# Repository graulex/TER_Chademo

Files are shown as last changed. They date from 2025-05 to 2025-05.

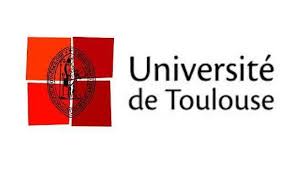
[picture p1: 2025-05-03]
Code/IHM/téléchargement.jpeg

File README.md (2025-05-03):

# Projet TER – Communication CAN avec STM32 pour la recharge CHAdeMO

##  Introduction

Ce dépôt GitHub présente le travail réalisé dans le cadre du **projet TER** intitulé :

**_Conception de cartes de communication CAN sur la base d’un microcontrôleur STM32 pour l’émulation de la gestion de charge de la voiture électrique avec le protocole CHAdeMO._**

Ce projet a été mené par :

- **Alexandre Guilcher**  
- **Damien Gonfo**  
- **Salah Ouaret**  

Sous la direction de **Damian Sal y Rosas**.

---

##  Organisation du dépôt

### `code/`
Contient l'ensemble des codes sources du projet :
-  **Code C STM32 - Borne de recharge (EVSE)** : développé avec STM32CubeIDE, implémente la logique de communication CHAdeMO côté borne.
-  **Code C STM32 - Véhicule électrique (EV)** : développé également sur STM32CubeIDE, simule le comportement d’un véhicule compatible CHAdeMO.
-  **Interface MATLAB** : IHM développée sous MATLAB permettant de communiquer avec la borne via une interface série (USART). Elle permet de lancer ou arrêter la charge et de suivre l’état de la batterie depuis un ordinateur.

---

### `documentation/`
Regroupe les ressources techniques utilisées :
-  **Articles scientifiques**
-  **Documentation technique officielle IEEE**

---

### `doxygen/`
Documentation logicielle générée automatiquement avec **Doxygen** :  
Décrit les fonctions, structures et comportements du code C (borne et véhicule).

---

### `uml/`
Diagrammes UML utilisés pendant la phase de conception :
- Diagrammes de cas d’usage
- Diagrammes de séquence
- Diagrammes de classes pour le logiciel embarqué de la borne et du véhicule
- Machines à états du véhicule et de la borne

---

### `kicad/`
Plans électroniques créés avec **KiCad** :
- 🛠 **Carte Borne de Recharge**
-  **Carte Véhicule Électrique**

Ces schémas permettent la fabrication physique des deux cartes de communication basées sur le protocole CAN.

---

##  Remarques

- Ce projet met en œuvre une **communication CAN bas-niveau**, conforme au protocole **CHAdeMO**, simulée entre une "borne" et un "véhicule" via des cartes STM32.
- L'IHM MATLAB agit comme un **outil de supervision et de contrôle**, permettant de **déclencher** et **suivre** une session de charge.

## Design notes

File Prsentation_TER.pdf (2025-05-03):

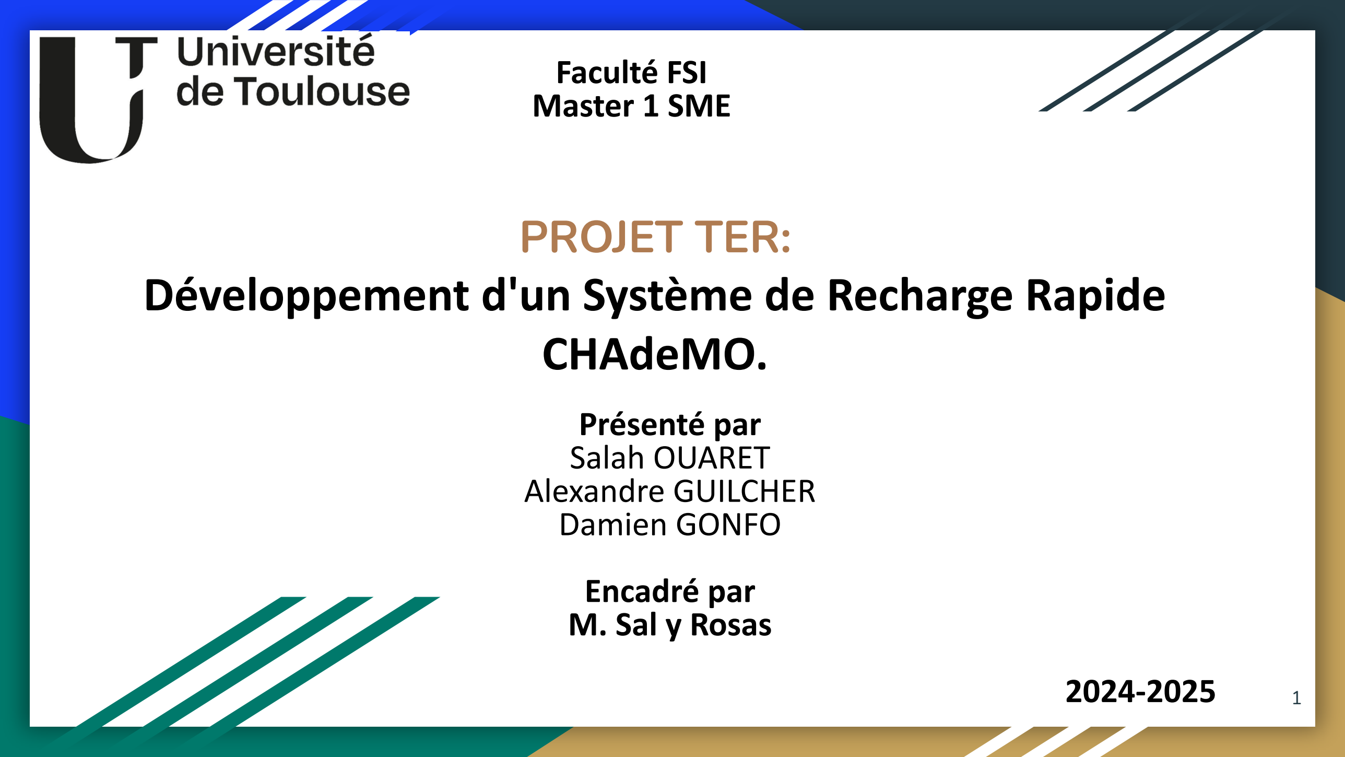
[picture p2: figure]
PROJET TER:; CHAdeMO.; Faculté FSI Master 1 SME; Présenté par Salah OUARET Alexandre GUILCHER Damien GONFO; Encadré par M. Sal y Rosas

## Développement d'un Système de Recharge Rapide

# Plan

### 1. Introduction

### 2. Etat de l’art

### 3. Analyse fonctionnelle

### 4. Protocole CHAdeMO

### 5. Présentation du montage

### 6. Trames CAN

### 7. Séquence de fonctionnement d’une recharge

### 8. Schématisation électronique

### 9. Conclusion

2

# 1. Introduction

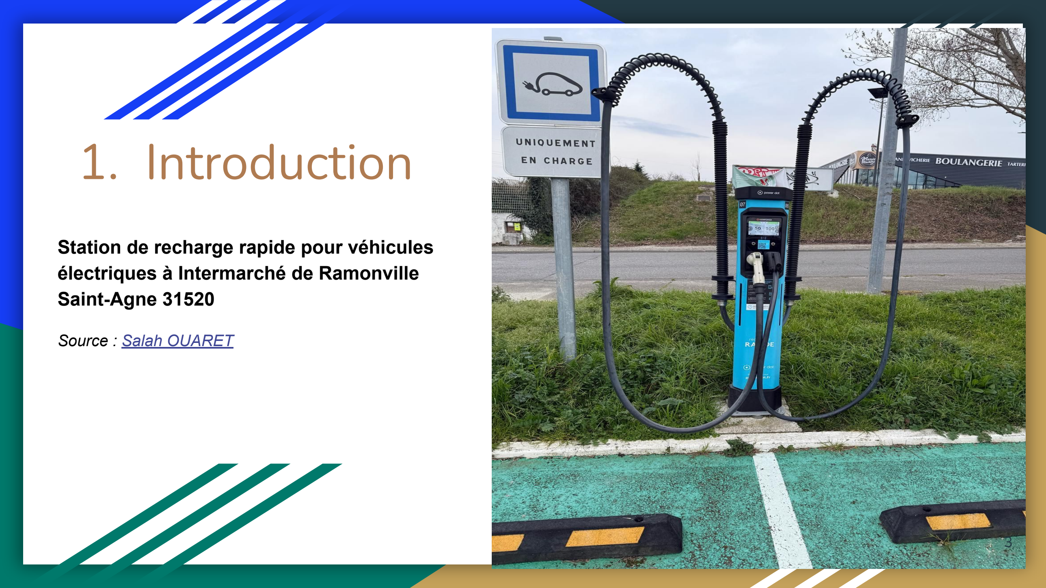
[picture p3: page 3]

Station de recharge rapide pour véhicules électriques à Intermarché de Ramonville Saint-Agne 31520

Source : Salah OUARET

3

# 2. Etat de l’art

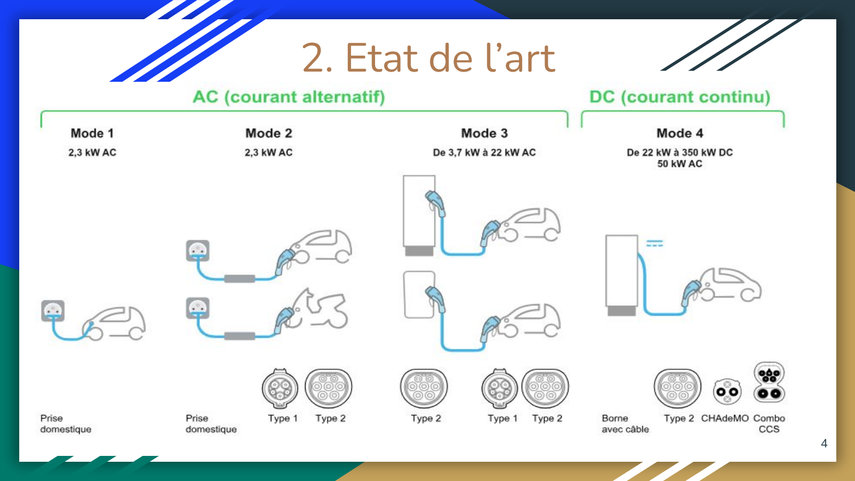
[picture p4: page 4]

4

# 3. Analyse fonctionnelle

5

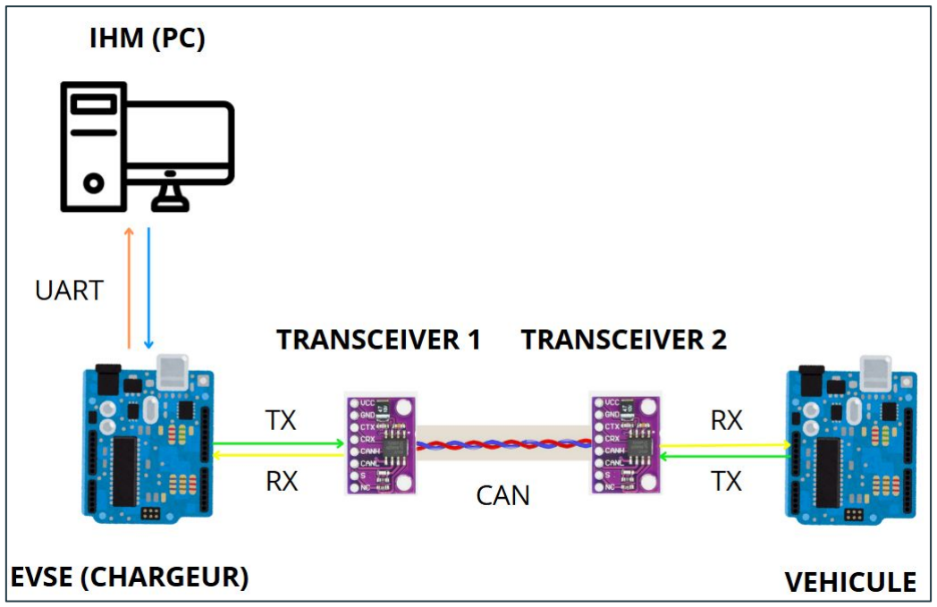
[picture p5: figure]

- Système composé de 2 cartes STM32 (EV et EVSE)
- Communication via bus CAN
- Machine à états pour gérer les phases de charge
- Exigences matérielles et logicielles (Interface IHM sous MATLAB, STM32CubeIDE)
- Diagrammes UML : contexte, cas d'utilisation, séquences

# 4. Protocole CHAdeMO

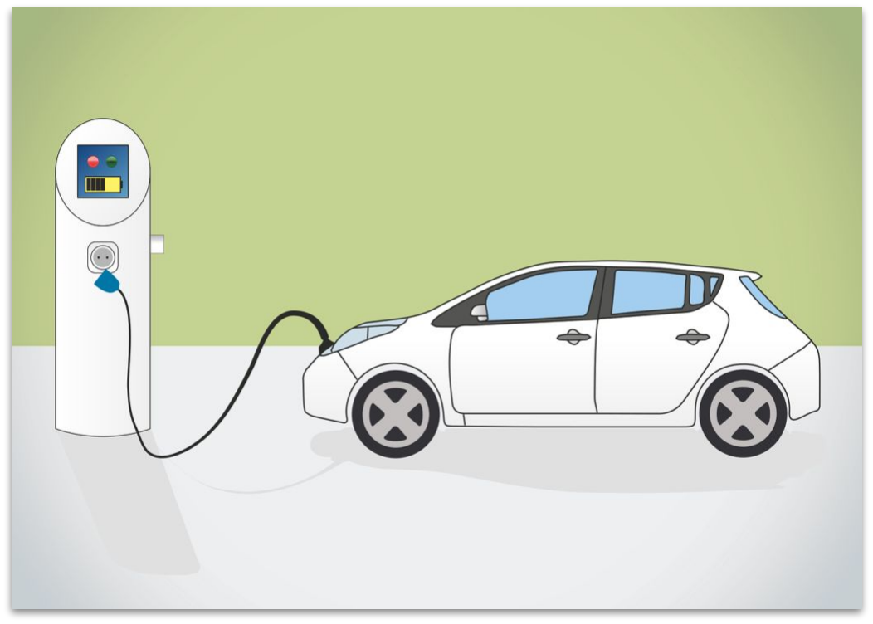
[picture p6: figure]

6

- Standard DC
- Communication CAN
- Échanges d’information véhicule / borne de recharge
- V2X : Vehicle to Everything
- V2G : Vehicle to Grid
- V2N : Vehicle to Network

# 5. Présentation du montage

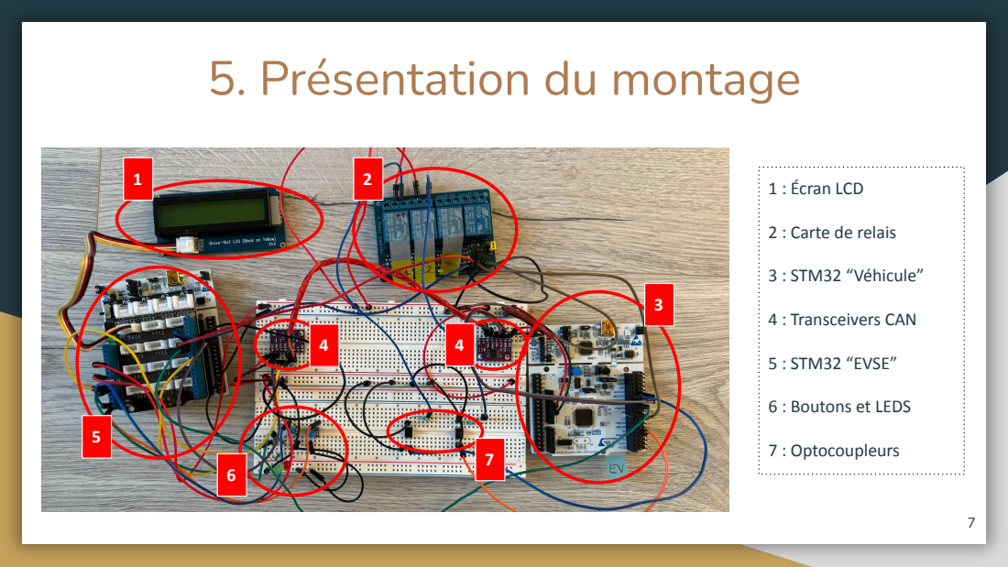
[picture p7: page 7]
1 : Écran LCD; 3 : STM32 “Véhicule”; 4 : Transceivers CAN; 5 : STM32 “EVSE”; 7 : Optocoupleurs

2 : Carte de relais

6 : Boutons et LEDS

# 6. Trames CAN

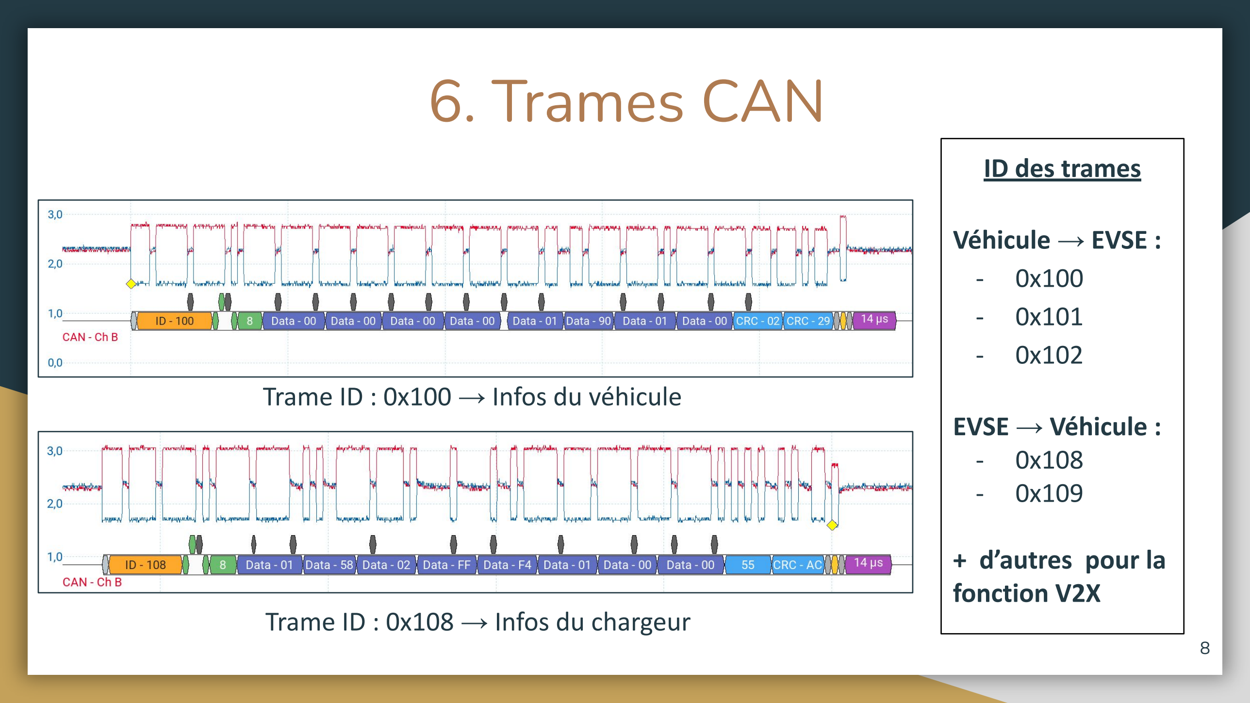
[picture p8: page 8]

ID des trames

Véhicule → EVSE :
- 0x100
- 0x101
- 0x102

EVSE → Véhicule :
- 0x108
- 0x109

+ d’autres pour la
fonction V2X

Trame ID : 0x100 → Infos du véhicule

Trame ID : 0x108 → Infos du chargeur
8

# 7. Séquence de fonctionnement d’une recharge

Signaux :
- d1 (Premier signal de séquence de charge)
- d2 (Second signal de séquence de charge)
- K (Permission de charge)
- CAN HIGH
- CAN LOW

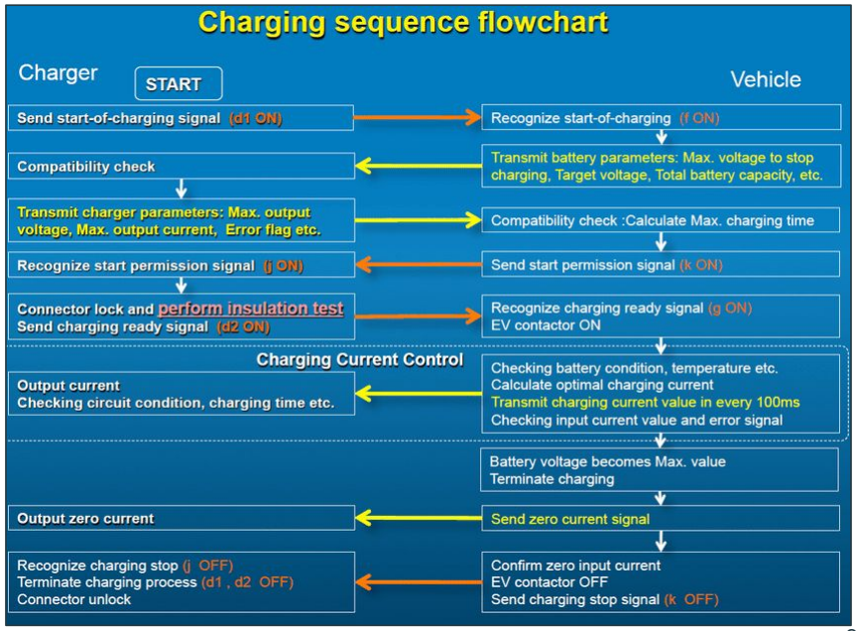
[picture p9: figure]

https://www.researchgate.net/figure/Flow-diagram-of-the-CHAdeMO-chagrining-protocol_fig4_319162700 9

# 8. Schéma électrique général

10

Configuration générale :

- EVSE (chargeur) et EV (véhicule)
- Positionnement des relais
- Références pour le CAN

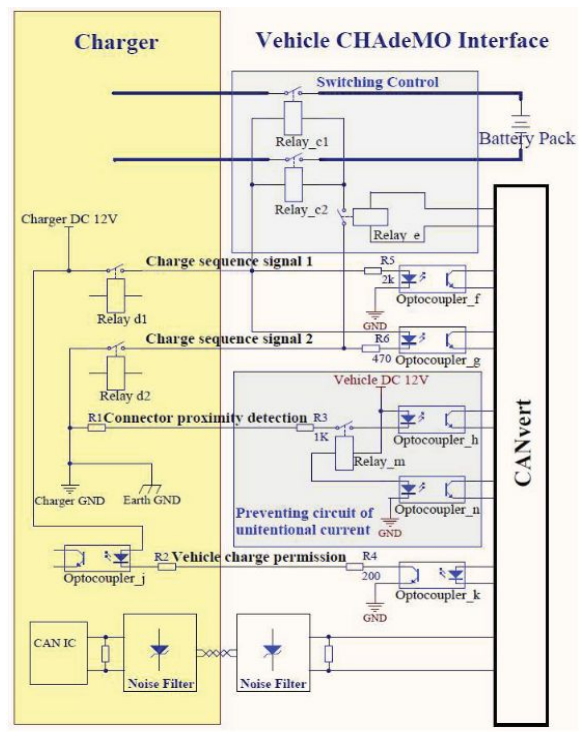
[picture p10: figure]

B.Sampath Kumar, Design and implementation of a CHAdeMO Interface on-board vehicle for vehicle-to-grid Applications, The International journal of analytical and experimental modal analysis

# 9. Schéma électrique partie EVSE

11

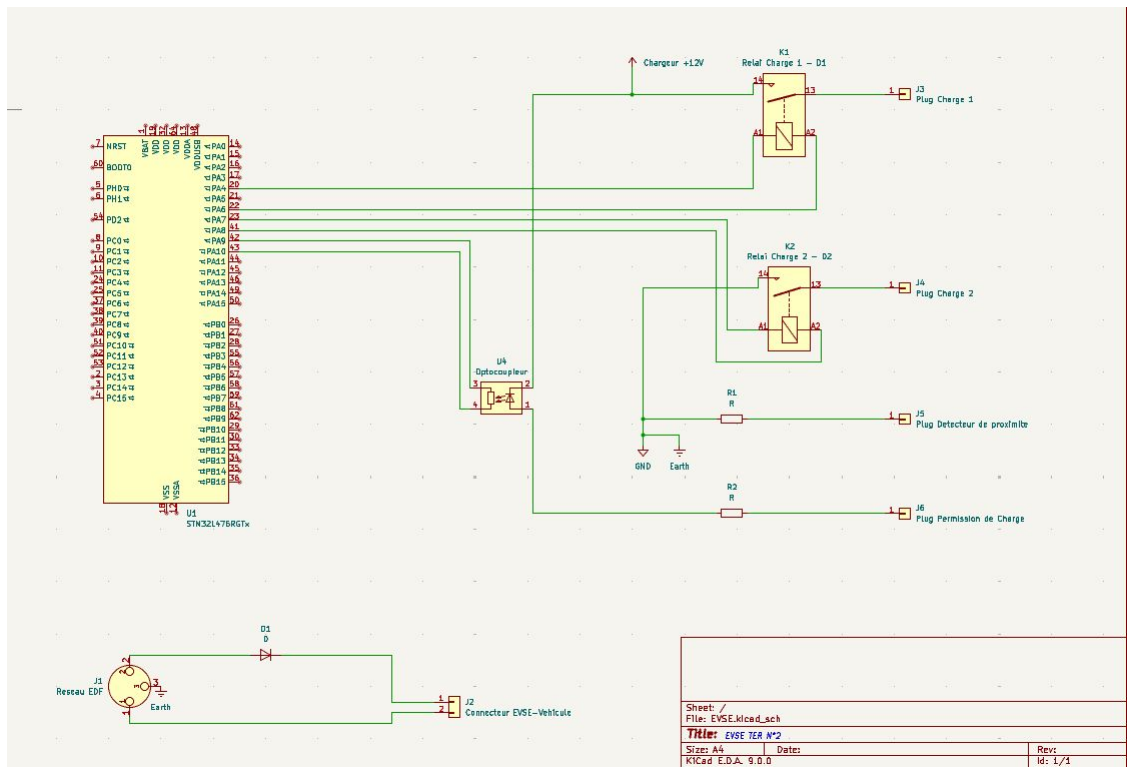
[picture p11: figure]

# 10. Modélisation 3D PCB partie EVSE

12

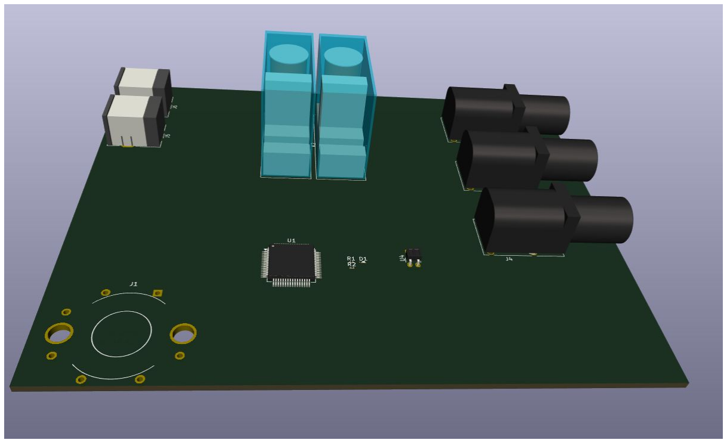
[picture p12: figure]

# 11. Schéma électrique partie EV

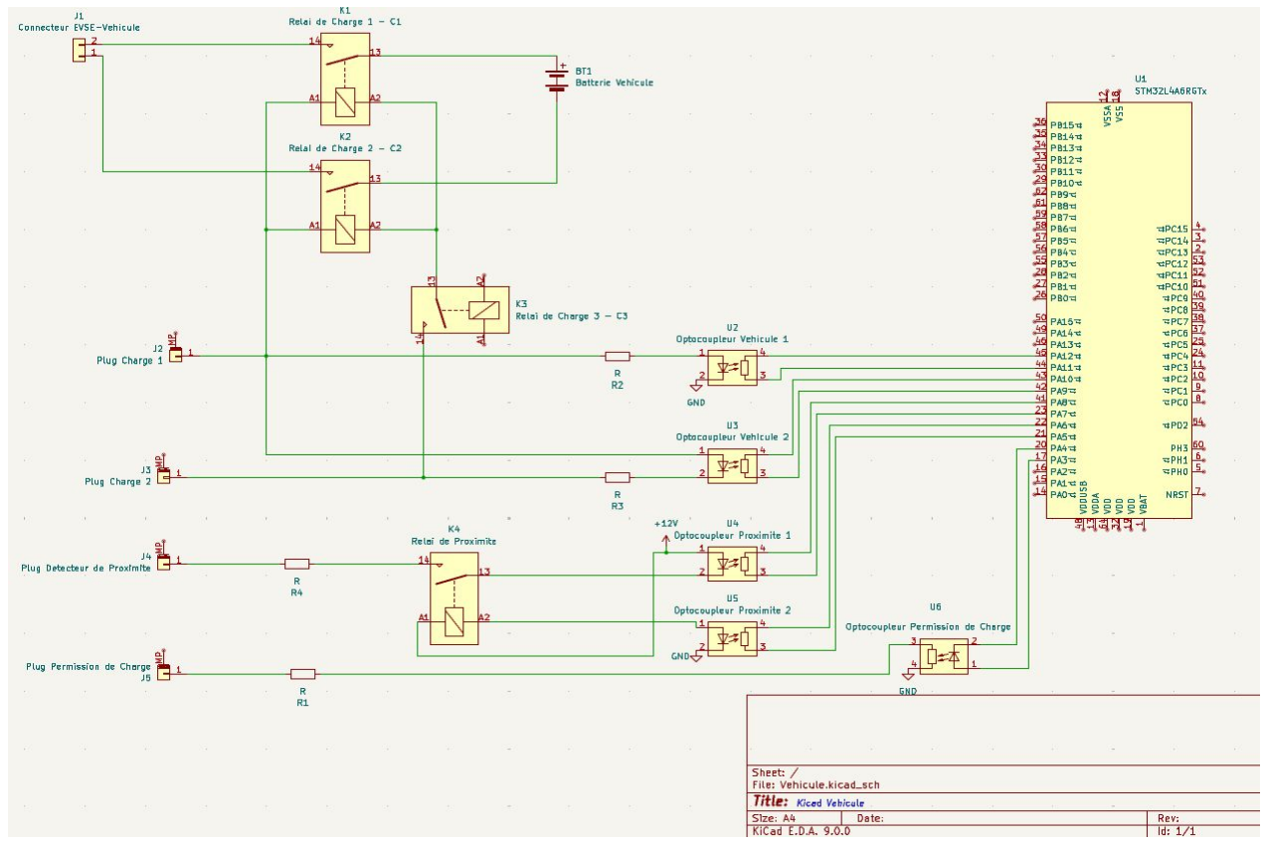
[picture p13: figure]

13

# 12. Modélisation 3D PCB partie EV

14

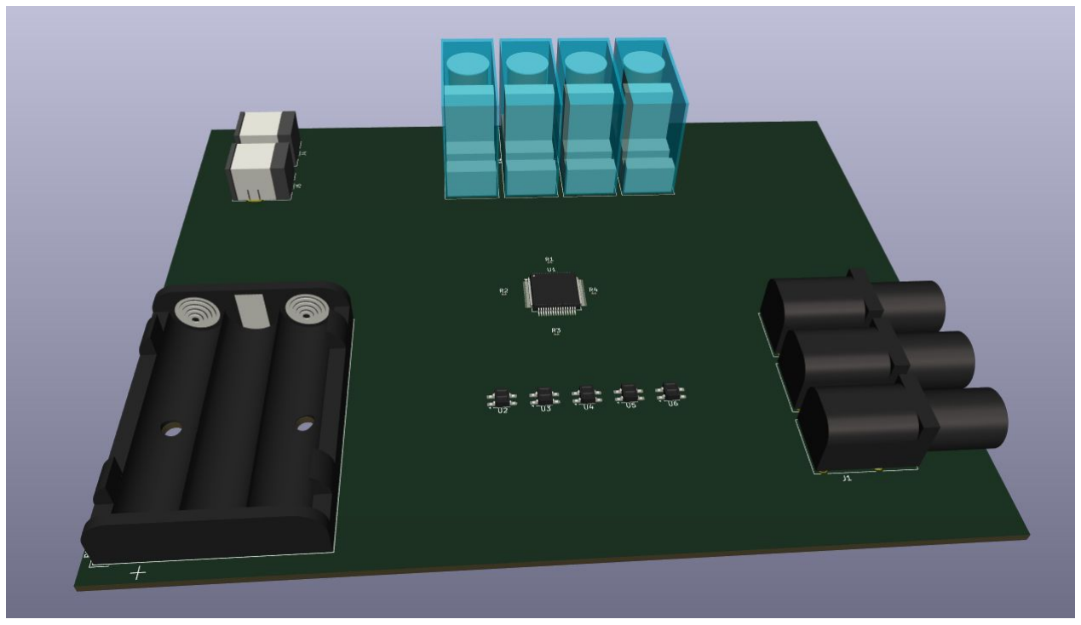
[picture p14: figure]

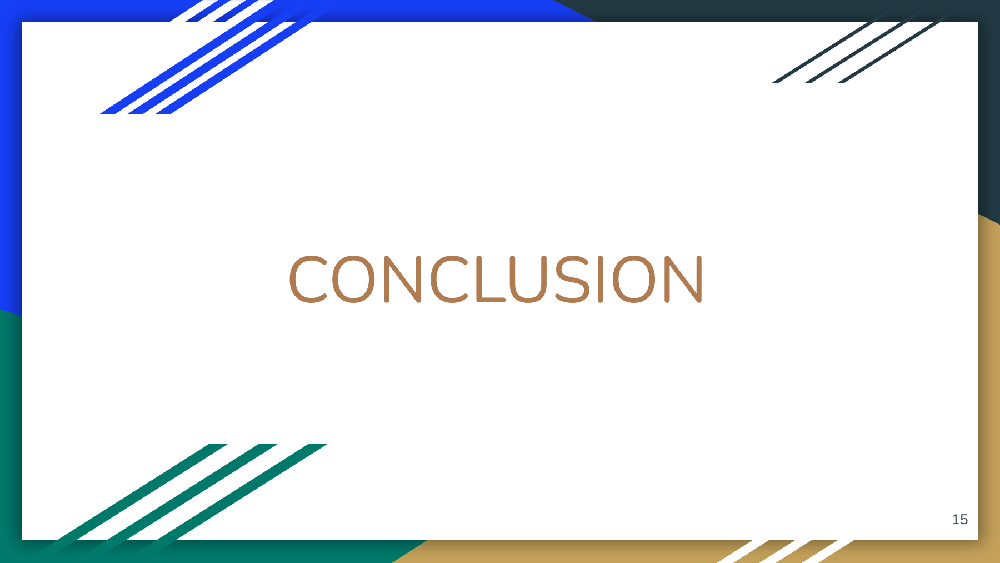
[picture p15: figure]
CONCLUSION

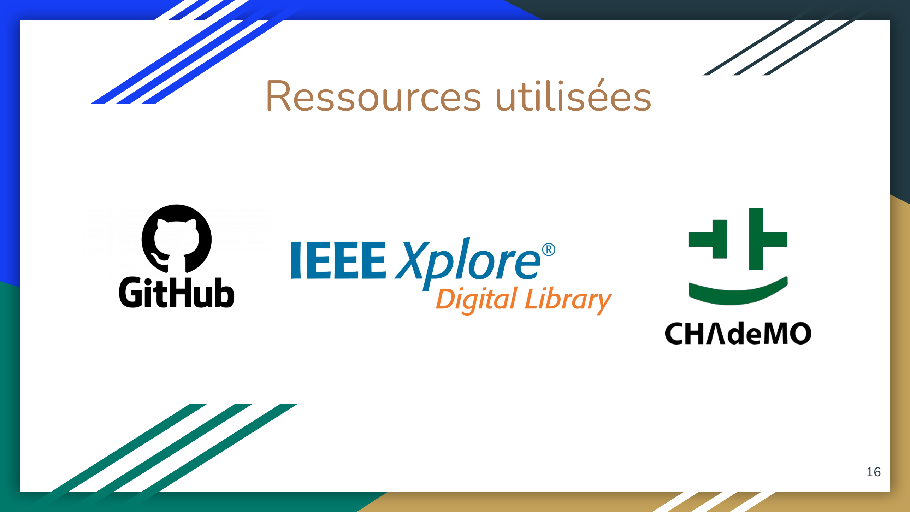
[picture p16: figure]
Ressources utilisées

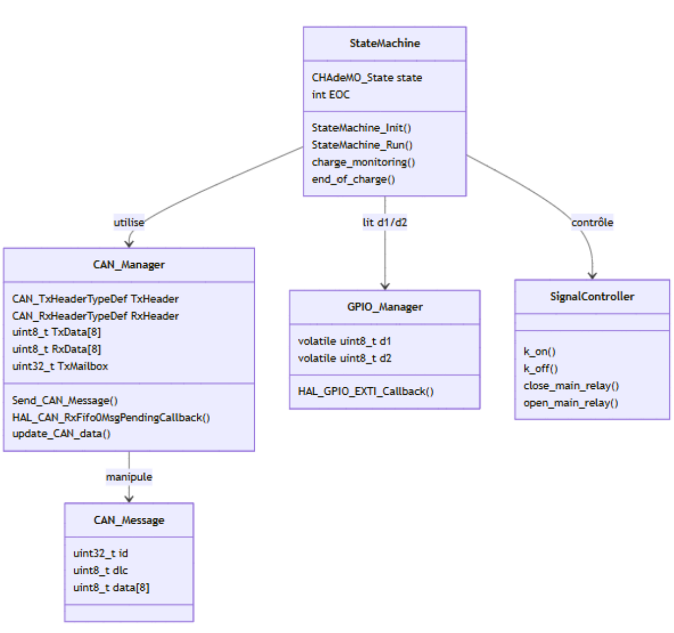
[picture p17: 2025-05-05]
Diagrammes UML/Diagramme de classes EV.png

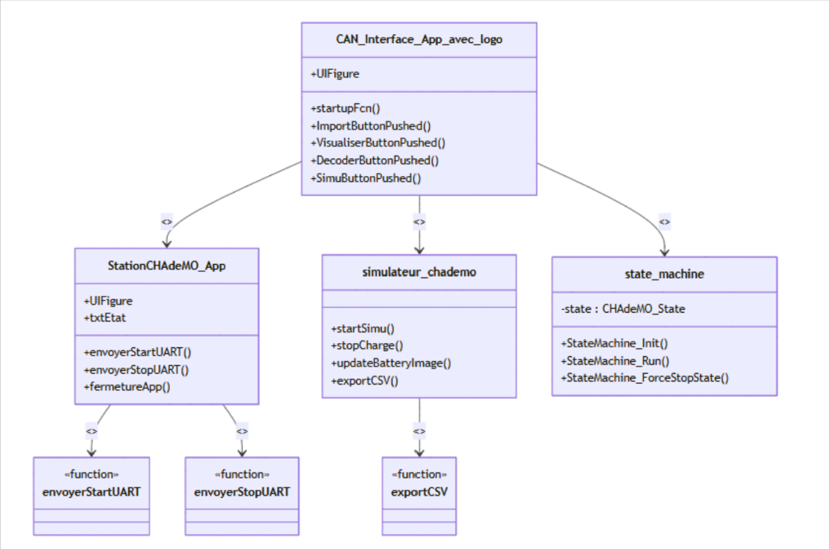
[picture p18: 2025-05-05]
Diagrammes UML/Diagramme de classes IHM.png

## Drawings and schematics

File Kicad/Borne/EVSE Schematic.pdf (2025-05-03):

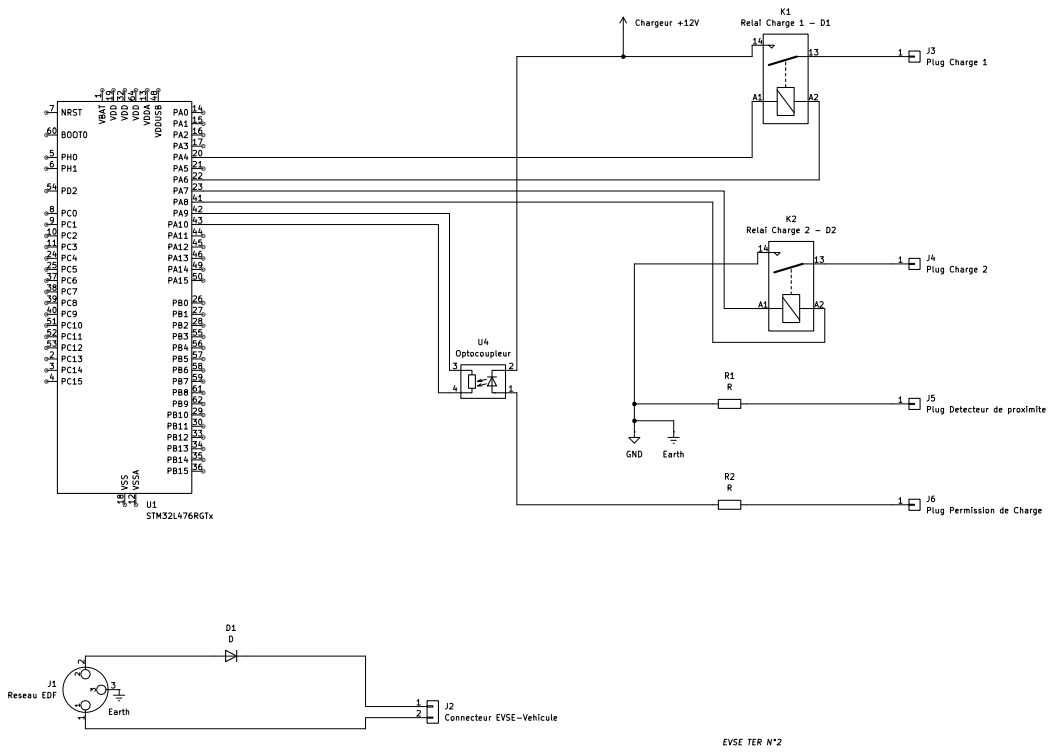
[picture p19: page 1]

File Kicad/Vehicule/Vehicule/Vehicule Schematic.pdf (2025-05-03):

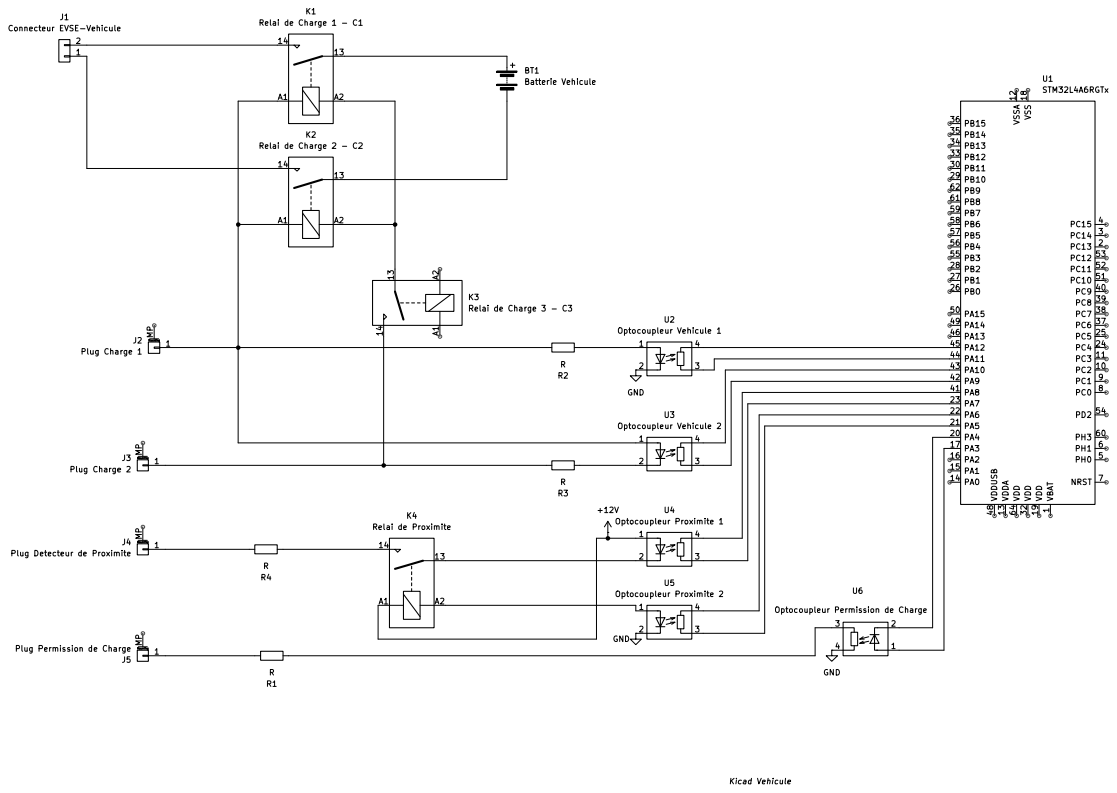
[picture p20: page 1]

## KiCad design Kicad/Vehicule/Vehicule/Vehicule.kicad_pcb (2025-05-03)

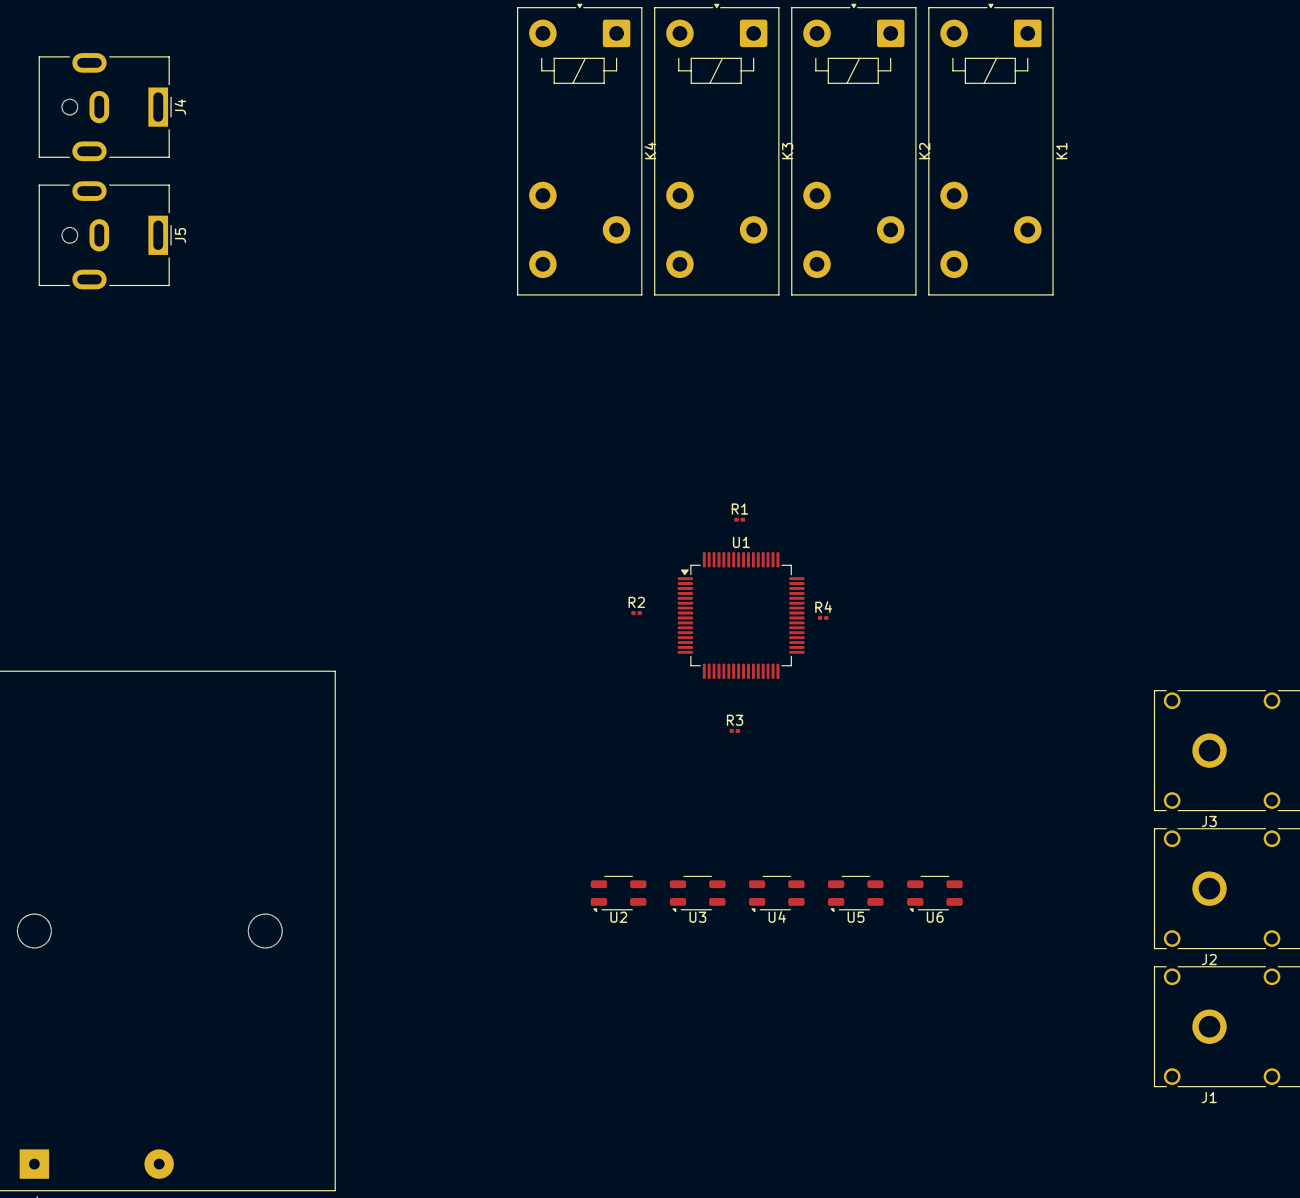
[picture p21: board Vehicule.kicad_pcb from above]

Board: 2 copper layers, 20 parts (0 on the bottom side), 24 nets, no tracks yet.

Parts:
BT1: Batterie Vehicule; BatteryHolder_Keystone_2479_3xAAA
J1: Connecteur EVSE-Vehicule; Banana_Cliff_FCR7350B_S16N-PC_Horizontal
J2: Plug Charge 1; Banana_Cliff_FCR7350B_S16N-PC_Horizontal
J3: Plug Charge 2; Banana_Cliff_FCR7350B_S16N-PC_Horizontal
J4: Plug Detecteur de Proximite; BarrelJack_CUI_PJ-063AH_Horizontal
J5: Plug Permission de Charge; BarrelJack_CUI_PJ-063AH_Horizontal
K1: Relai de Charge 1 - C1; Relay_SPDT_Finder_40.31
K2: Relai de Charge 2 - C2; Relay_SPDT_Finder_40.31
K3: Relai de Charge 3 - C3; Relay_SPDT_Finder_40.31
K4: Relai de Proximite; Relay_SPDT_Finder_40.31
R1, R2, R3, R4: R; R_0201_0603Metric
U1: STM32L4A6RGTx; LQFP-64_10x10mm_P0.5mm
U2: Optocoupleur Vehicule 1; OnSemi_CASE100CY
U3: Optocoupleur Vehicule 2; OnSemi_CASE100CY
U4: Optocoupleur Proximite 1; OnSemi_CASE100CY
U5: Optocoupleur Proximite 2; OnSemi_CASE100CY
U6: Optocoupleur Permission de Charge; OnSemi_CASE100CY

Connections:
+12V: K4.A1, U4.1 (A)
GND: U2.2 (K), U5.2 (K), U6.4 (R)
unnamed: J1.1, K2.14
unnamed: J2.1, K1.A1, K2.A1, R2.2, U3.1 (A)
unnamed: J3.1, K3.14, R3.2
unnamed: J4.1, R4.2
unnamed: J5.1, R1.2
unnamed: K1.A2, K2.A2
unnamed: K4.14, R4.1
unnamed: R1.1, U6.3 (R)
unnamed: U1.17 (PA3), U6.1 (A)
unnamed: U1.20 (PA4), U6.2 (K)
unnamed: U1.21 (PA5), U5.3 (R)
unnamed: U1.22 (PA6), U5.4 (R)
unnamed: U1.23 (PA7), U4.3 (R)
unnamed: U1.41 (PA8), U4.4 (R)
unnamed: U1.42 (PA9), U3.3 (R)
unnamed: U1.43 (PA10), U3.4 (R)
unnamed: U1.44 (PA11), U2.3 (R)
unnamed: U1.45 (PA12), U2.4 (R)
unnamed: U1.18 (VSS), U1.31 (VSS), U1.47 (VSS), U1.63 (VSS)
unnamed: R2.1, U2.1 (A)
unnamed: R3.1, U3.2 (K)
unnamed: K4.A2, U5.1 (A)

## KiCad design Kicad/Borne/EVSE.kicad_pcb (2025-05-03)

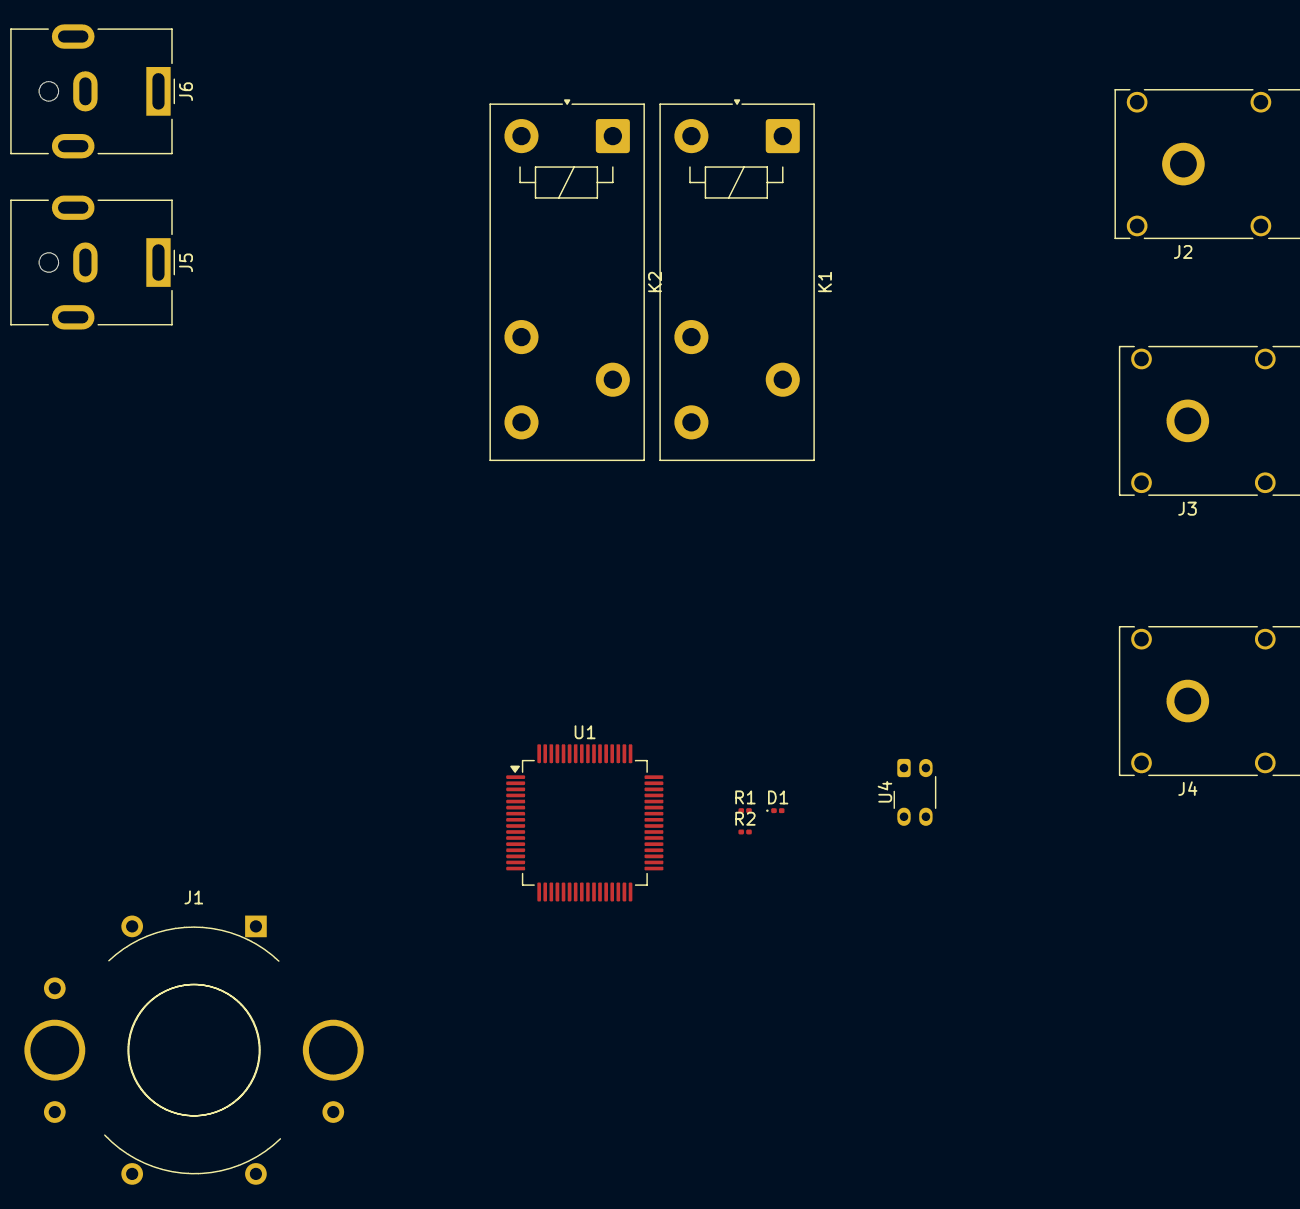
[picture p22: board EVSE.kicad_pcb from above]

Board: 2 copper layers, 13 parts (0 on the bottom side), 14 nets, no tracks yet.

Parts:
D1: D; LED_0201_0603Metric
J1: Reseau EDF; Valve_Mini_G
J2: Connecteur EVSE-Vehicule; Banana_Cliff_FCR7350B_S16N-PC_Horizontal
J3: Plug Charge 1; Banana_Cliff_FCR7350B_S16N-PC_Horizontal
J4: Plug Charge 2; Banana_Cliff_FCR7350B_S16N-PC_Horizontal
J5: Plug Detecteur de proximite; BarrelJack_CUI_PJ-063AH_Horizontal
J6: Plug Permission de Charge; BarrelJack_CUI_PJ-063AH_Horizontal
K1: Relai Charge 1 - D1; Relay_SPDT_Finder_40.31
K2: Relai Charge 2 - D2; Relay_SPDT_Finder_40.31
R1, R2: R; R_0201_0603Metric
U1: STM32L476RGTx; LQFP-64_10x10mm_P0.5mm
U4: Optocoupleur; Kodenshi_SG105F

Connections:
Chargeur +12V: K1.14, U4.2 (K)
Earth: J1.3, K2.14, R1.1
unnamed: D1.2 (A), J1.2
unnamed: D1.1 (K), J2.1
unnamed: J5.1, R1.2
unnamed: J6.1, R2.2
unnamed: K1.A1, U1.20 (PA4)
unnamed: K1.A2, U1.22 (PA6)
unnamed: K2.A1, U1.23 (PA7)
unnamed: K2.A2, U1.41 (PA8)
unnamed: U1.42 (PA9), U4.3 (R)
unnamed: U1.43 (PA10), U4.4 (R)
unnamed: U1.18 (VSS), U1.31 (VSS), U1.47 (VSS), U1.63 (VSS)
unnamed: R2.1, U4.1 (A)

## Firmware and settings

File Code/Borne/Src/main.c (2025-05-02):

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
/* Includes ------------------------------------------------------------------*/
#include "main.h"
#include "can.h"
#include "i2c.h"
#include "usart.h"
#include "gpio.h"

/* USER CODE BEGIN Includes */
#include "ui.h"
#include "lcd1.h"
#include "signals.h"
#include "state_machine.h"
#include <stdio.h>


/* USER CODE END Includes */

/* USER CODE BEGIN PD */
static rgb_lcd lcdData;

/* USER CODE END PD */


void SystemClock_Config(void);
/**
  * @brief  The application entry point.
  * @retval int
  */
int main(void)
{

  /* MCU Configuration--------------------------------------------------------*/

  /* Reset of all peripherals, Initializes the Flash interface and the Systick. */
  HAL_Init();

  /* Configure the system clock */
  SystemClock_Config();

  /* Initialize all configured peripherals */
  MX_GPIO_Init();
  MX_USART2_UART_Init();
  MX_CAN1_Init();
  MX_I2C1_Init();
  /* USER CODE BEGIN 2 */
  lcd_init(&hi2c1, &lcdData);
  StateMachine_Init();
  HAL_CAN_Start(&hcan1);
  HAL_CAN_ActivateNotification(&hcan1, CAN_IT_RX_FIFO0_MSG_PENDING);
  HAL_UART_Receive_IT(&huart2, &rx_data, 1);
  /* USER CODE END 2 */

  /* Infinite loop */
  /* USER CODE BEGIN WHILE */
  while (1)
  {
    /* USER CODE END WHILE */

    /* USER CODE BEGIN 3 */
	  StateMachine_Run(); //Appelle la fonction de machine à état
	  HAL_Delay(100);

  }
  /* USER CODE END 3 */
}

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


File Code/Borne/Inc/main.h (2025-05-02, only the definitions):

#define BP_START_Pin GPIO_PIN_0
#define BP_START_GPIO_Port GPIOC
#define BP_START_EXTI_IRQn EXTI0_IRQn
#define BP_STOP_Pin GPIO_PIN_1
#define BP_STOP_GPIO_Port GPIOC
#define BP_STOP_EXTI_IRQn EXTI1_IRQn
#define LED_CHARGE_Pin GPIO_PIN_0
#define LED_CHARGE_GPIO_Port GPIOA
#define LED_ERREUR_Pin GPIO_PIN_1
#define LED_ERREUR_GPIO_Port GPIOA
#define USART_TX_Pin GPIO_PIN_2
#define USART_TX_GPIO_Port GPIOA
#define USART_RX_Pin GPIO_PIN_3
#define USART_RX_GPIO_Port GPIOA
#define RELAY_Pin GPIO_PIN_4
#define RELAY_GPIO_Port GPIOA
#define LD2_Pin GPIO_PIN_5
#define LD2_GPIO_Port GPIOA
#define d1_Pin GPIO_PIN_6
#define d1_GPIO_Port GPIOA
#define d2_Pin GPIO_PIN_7
#define d2_GPIO_Port GPIOA
#define TMS_Pin GPIO_PIN_13
#define TMS_GPIO_Port GPIOA
#define TCK_Pin GPIO_PIN_14
#define TCK_GPIO_Port GPIOA
#define SWO_Pin GPIO_PIN_3
#define SWO_GPIO_Port GPIOB
#define j_Pin GPIO_PIN_6
#define j_GPIO_Port GPIOB
#define j_EXTI_IRQn EXTI9_5_IRQn
#define LCD_SCL_Pin GPIO_PIN_8
#define LCD_SCL_GPIO_Port GPIOB
#define LCD_SDA_Pin GPIO_PIN_9
#define LCD_SDA_GPIO_Port GPIOB

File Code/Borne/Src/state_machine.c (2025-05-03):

#include "state_machine.h"

// Structure de gestion de l'écran LCD I2C
static rgb_lcd lcdData;

// Mémorise l’état précédent de J (permet de détecter une transition de 1 → 0)
uint8_t J_previous = 0;

// État courant de la machine d’état
CHAdeMO_State state = IDLE;

/**
 * Force l'arrêt immédiat de la machine d'état.
 */
void StateMachine_ForceStopState() {
    state = STOP;
}

/**
 * Initialise la machine d’état (mise à IDLE).
 */
void StateMachine_Init() {
    state = IDLE;
}

/**
 * Exécute la machine d’état.
 */
void StateMachine_Run() {
    switch (state) {

        // Attente de l’appui sur le bouton START
        case IDLE:
        	affiche_lcd(&hi2c1,&lcdData,"App START");

        	if (START == 1) {
                state = BATT_COMPATIBILITY;
                START = 0;

                // Fermeture du relais D1
                affiche_lcd(&hi2c1,&lcdData,"Fermeture d1");
                dx_on(D1);
                HAL_Delay(1000);
            }
            break;

        // Vérification de la compatibilité batterie/chargeur
        case BATT_COMPATIBILITY:
        	if (BATT_CHECK == 1) { // Batterie compatible
        		state = CHARGE_PERMISSION;
        		affiche_lcd(&hi2c1,&lcdData,"batt check ok");
        		HAL_Delay(1000);

        		// Envoi des paramètres de charge vers EVSE
        		Send_CAN_Message(&hcan1, evse_charge_param.id, evse_charge_param.data, evse_charge_param.dlc);
        	}
        	else {
        		// Batterie incompatible → arrêt
        		state = TERMINATING;
        		affiche_lcd(&hi2c1,&lcdData,"batt incompatible");
        		HAL_Delay(1000);
        	}
            break;

        // Attente de la permission de charge (ligne J à 1)
        case CHARGE_PERMISSION:
            if (J == 1) {
                state = CHARGING;
                affiche_lcd(&hi2c1,&lcdData,"Ferm. port charge");

                // Fermeture de D2 (lancement de la charge)
                dx_off(D2);
                HAL_Delay(1000);
            }
            break;

        // Boucle de charge : gestion active de la charge tant que CHARGE_ENABLE == 1
        case CHARGING: {
            J_previous = J;
            ui_led_on(LED_CHARGE);
            uint8_t charge_percent = 0;

            while (CHARGE_ENABLE == 1 && state == CHARGING) {

                // Affiche le pourcentage de charge simulé
                char buffer[32];
                sprintf(buffer, "Charge: %d %%", charge_percent);
                affiche_lcd(&hi2c1, &lcdData, buffer);

                HAL_Delay(80); // Délai entre deux "incréments" de charge

                // Incrément de charge simulé
                if (charge_percent < 100) {
                    charge_percent++;
                }

                // Arrêt si déconnexion de la ligne J (J passe de 1 à 0)
                if ((J == 0) && (J_previous == 1)) {
                    state = TERMINATING;
                    break;
                }

                // Arrêt si appui bouton STOP (GPIOC_PIN_1 à 0) ou STOP logiciel
                if ((HAL_GPIO_ReadPin(GPIOC, GPIO_PIN_1) == 0) || (STOP1 == 1)) {
                    state = STOP;
                    STOP1 = 0;
                    break;
                }
            }
            break;
        }

        // Fin de charge : extinction des LEDs, ouverture des relais
        case TERMINATING:
        	ui_led_off(LED_CHARGE);
        	dx_on(D2);   // Ouvre D2
        	dx_off(D1);  // Ouvre D1
        	affiche_lcd(&hi2c1,&lcdData,"Fin de charge");
        	HAL_Delay(5000);
            state = IDLE;
            break;

        // Mode STOP : erreur ou arrêt d’urgence
        case STOP: {
            affiche_lcd(&hi2c1, &lcdData, "STOP");

            // Sécurité : couper relais et LED
            ui_led_off(LED_CHARGE);
            dx_on(D2);
            dx_off(D1);

            // Clignotement LED erreur pendant 5 secondes
            uint32_t startTime = HAL_GetTick();
            while ((HAL_GetTick() - startTime) < 5000) {
                ui_led_on(LED_ERREUR);
                HAL_Delay(200);
                ui_led_off(LED_ERREUR);
                HAL_Delay(200);
            }

            // Retour à l'état IDLE
            state = IDLE;
            break;
        }
    }
}

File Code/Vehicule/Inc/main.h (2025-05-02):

/**
  ******************************************************************************
  * @file           : main.h
  * @brief          : En-tête pour le fichier main.c.
  *                   Ce fichier contient les définitions globales du projet.
  *
  * @attention
  * Copyright (c) 2025 STMicroelectronics.
  * Tous droits réservés.
  * Ce logiciel est distribué selon les termes de la licence présente dans le
  * dossier racine du projet. À défaut, ce logiciel est fourni tel quel ("AS-IS").
  ******************************************************************************
  */

#ifndef __MAIN_H
#define __MAIN_H

#ifdef __cplusplus
extern "C" {
#endif

#include "stm32l4xx_hal.h"

/** @defgroup Constantes_Charge_Batterie
  * @brief Constantes spécifiques à la batterie EV
  * @{
  */
#define VMAX_BATT_EV 400  /**< Tension maximale de charge de la batterie (en Volts) */
#define IMAX_BATT_EV 125  /**< Courant maximal de charge de la batterie (en Ampères) */
/** @} */

/**
 * @brief Fonction appelée en cas d’erreur critique du système.
 */
void Error_Handler(void);

/** @defgroup GPIO_Definitions
  * @brief Définition des broches utilisées dans le projet
  * @{
  */
#define B1_Pin             GPIO_PIN_13
#define B1_GPIO_Port       GPIOC

#define USART_TX_Pin       GPIO_PIN_2
#define USART_TX_GPIO_Port GPIOA

#define USART_RX_Pin       GPIO_PIN_3
#define USART_RX_GPIO_Port GPIOA

#define LD2_Pin            GPIO_PIN_5
#define LD2_GPIO_Port      GPIOA

#define d1_Pin             GPIO_PIN_6        /**< Entrée déclenchement D1 (interruption) */
#define d1_GPIO_Port       GPIOA
#define d1_EXTI_IRQn       EXTI9_5_IRQn

#define main_relay_Pin     GPIO_PIN_9        /**< Sortie pour le relais principal */
#define main_relay_GPIO_Port GPIOA

#define TMS_Pin            GPIO_PIN_13
#define TMS_GPIO_Port      GPIOA

#define TCK_Pin            GPIO_PIN_14
#define TCK_GPIO_Port      GPIOA

#define SWO_Pin            GPIO_PIN_3
#define SWO_GPIO_Port      GPIOB

#define d2_Pin             GPIO_PIN_4        /**< Entrée déclenchement D2 (interruption) */
#define d2_GPIO_Port       GPIOB
#define d2_EXTI_IRQn       EXTI4_IRQn

#define k_Pin              GPIO_PIN_6        /**< Sortie commande signal K */
#define k_GPIO_Port        GPIOB
/** @} */

#ifdef __cplusplus
}
#endif

#endif /* __MAIN_H */

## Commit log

2025-05-03 Ajout de documentation, digrammes UML (MEF) et changement sur Doxygen
    [donnees_charge.csv]
2025-05-03 Ajout fichiers Kicad
    [EVSE.kicad_pcb, EVSE.kicad_sch, Vehicule.kicad_pcb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]

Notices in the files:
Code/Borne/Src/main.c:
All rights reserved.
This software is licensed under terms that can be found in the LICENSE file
